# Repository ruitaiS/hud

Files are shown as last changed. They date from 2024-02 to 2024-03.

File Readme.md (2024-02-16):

## 2-15:

<div style="display: inline-block;">
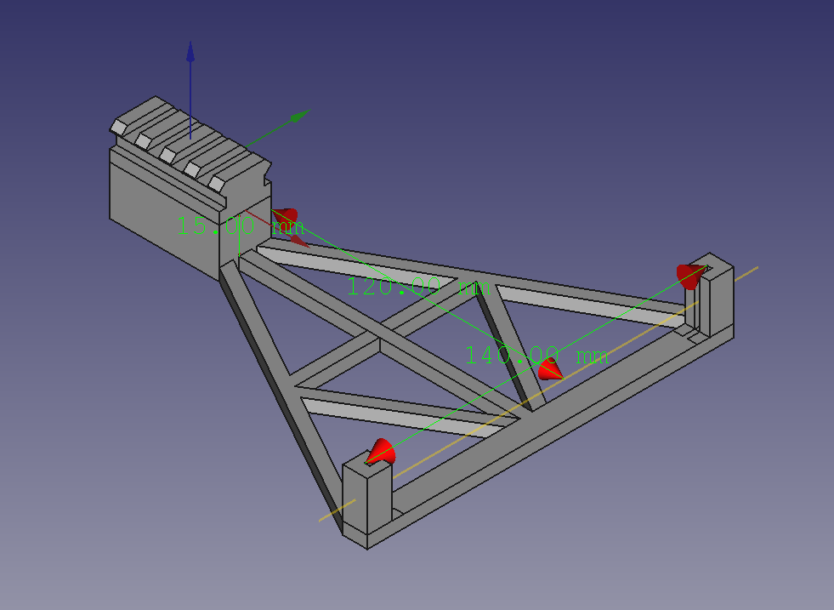
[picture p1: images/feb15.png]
    
    
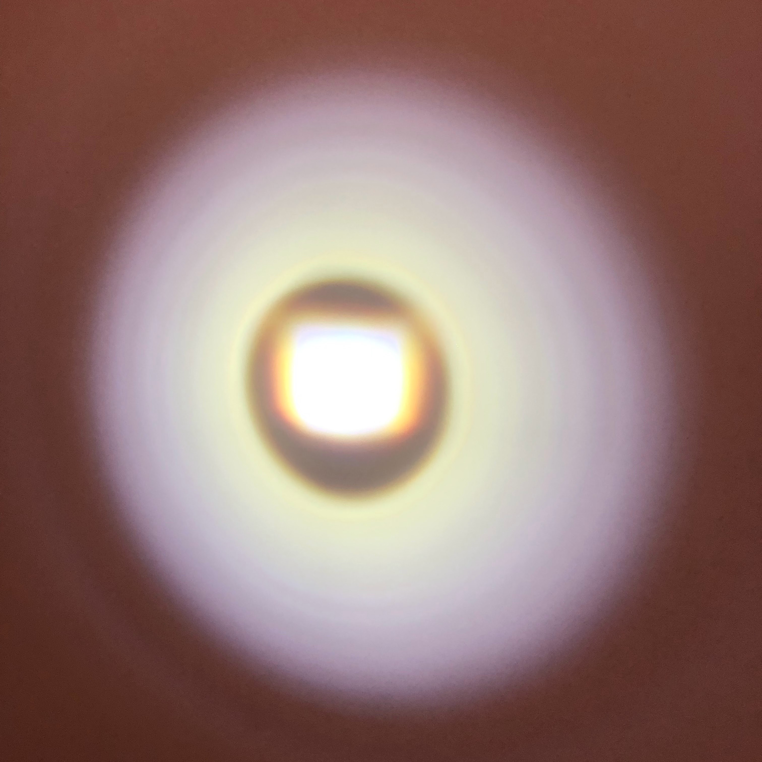
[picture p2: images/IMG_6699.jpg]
    
</div>

### Notes:
Nice. Bracket fits, and I think the focal length is roughly correct. I think that's what it means when the LED stays in focus as I move it back and forth; tbh I don't understand optics super well. I think the projected light pattern is caused by the mirror in the LED housing bouncing the light at weird angles to the collimator lens (you can see the square LED itself in the center, surrounded by a halo), so next steps will be to take that off and design some way to make finer adjustments for focal length.

### Changes:
- Lens bracket width fixed
- Light mount height offset increased from 0 to 15mm
- Infill Density reduced from 100% to 10%

### Print Settings:
Layer Height: 0.12 mm  
Wall Thickness: 1.2 mm  
Wall Line Count: 8  
Horizontal Expansion: 0.0 mm  
Top/Bottom Thickness: 0.84 mm  
Top Thickness: 0.84 mm  
Top Layers: 7  
Bottom Thickness: 0.84 mm  
Bottom Layers: 7  
Infill Density: 10%  
Infill Pattern: Gyroid  
Printing Temperature: 220.0 C  
Build Plate Temperature: 60.0 C  
Print Speed 45.0 mm/s  
Fan Speed 100%  
Generate Support: True  
Support Placement: Everywhere  
Support Overhang Angle: 59.0 Deg.  
Support Horizontal Expansion: 0.8 mm  
Build Plate Adhesion Type: None 

## 2-14:

<div style="display: inline-block;">
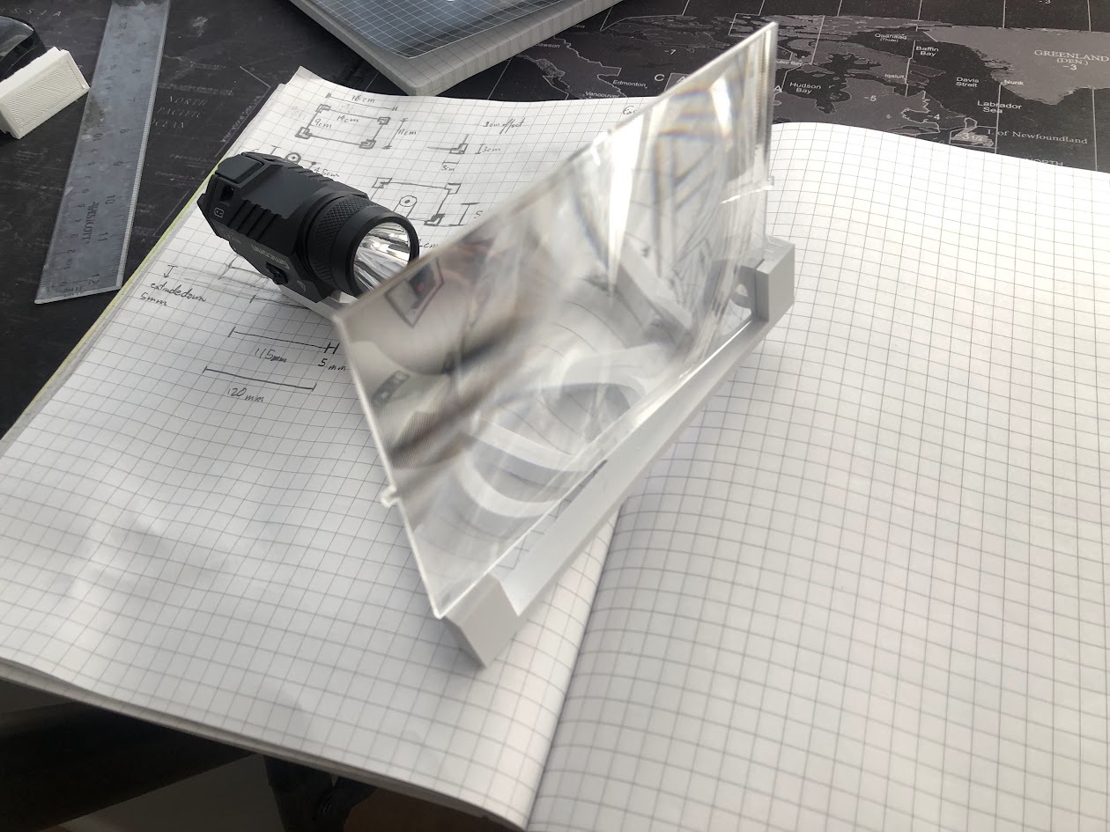
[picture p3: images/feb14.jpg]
    
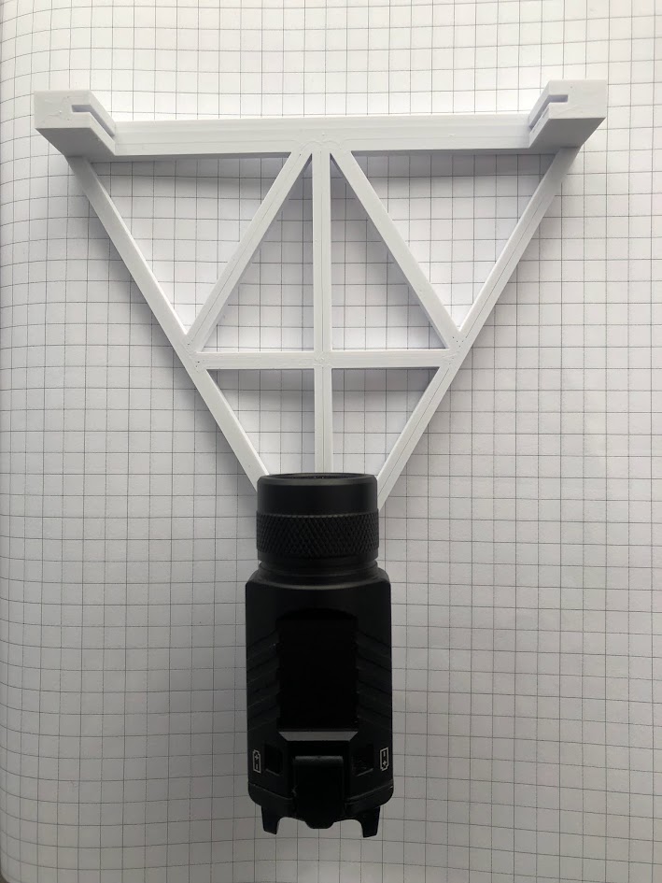
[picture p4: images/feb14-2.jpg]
    
</div>

### Notes:
I forgot to check the lens bracket width before printing it, so it didn't actually fit. Fixed it now, but it was kind of a foolish oversight. Not a total waste of time though; it was good to at least see a rough version irl and see what works and what needs fixed. The light mount was 15mm low after checking with a ruler; I'd originally calculated it by doing the height minus half the diameter of the housing, but it was easier to get a more accurate reading off the print. The rigidity is really good; triangles are really strong, so I'm pretty happy about that. A future project might be an analysis on the strength of different sized struts under tension / compression / bending, but for now good enough is good enough. Next print I'll try 10% infill; the struts and mounting points will still be solid because of the high wall count, but it'll save some time/material not filling in the bigger blocks. Build plate adhesion was fine; I was concerned because I couldn't fit a raft due to size constraints, but it turned out okay, so great.

### Print Settings:
Layer Height: 0.12 mm  
Wall Thickness: 1.2 mm  
Wall Line Count: 8  
Horizontal Expansion: 0.0 mm  
Top/Bottom Thickness: 0.84 mm  
Top Thickness: 0.84 mm  
Top Layers: 7  
Bottom Thickness: 0.84 mm  
Bottom Layers: 7  
Infill Density: 100%  
Infill Pattern: Gyroid  
Printing Temperature: 220.0 C  
Build Plate Temperature: 60.0 C  
Print Speed 45.0 mm/s  
Fan Speed 100%  
Generate Support: True  
Support Placement: Everywhere  
Support Overhang Angle: 59.0 Deg.  
Support Horizontal Expansion: 0.8 mm  
Build Plate Adhesion Type: None

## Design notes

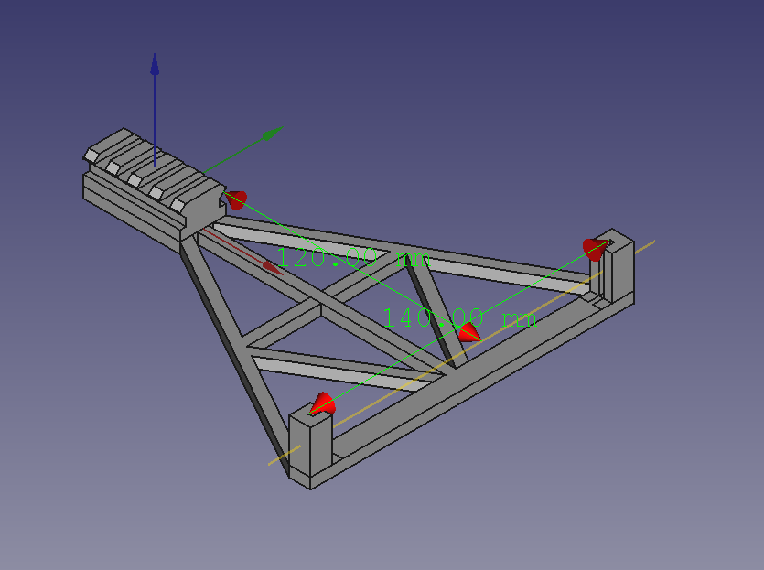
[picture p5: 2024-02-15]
images/combined.png

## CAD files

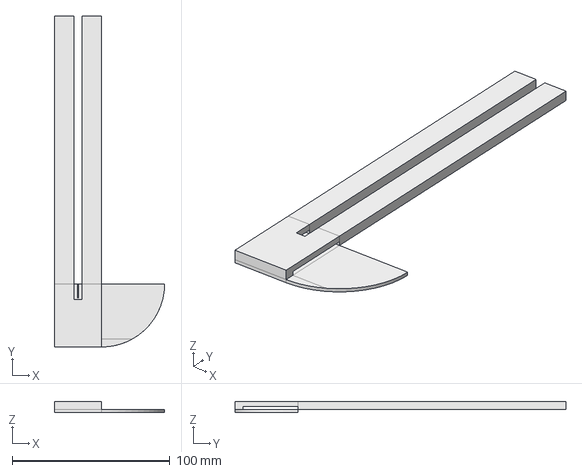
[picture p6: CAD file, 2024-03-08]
cutting-guide.FCStd
70.0 x 210.0 x 6.70 mm

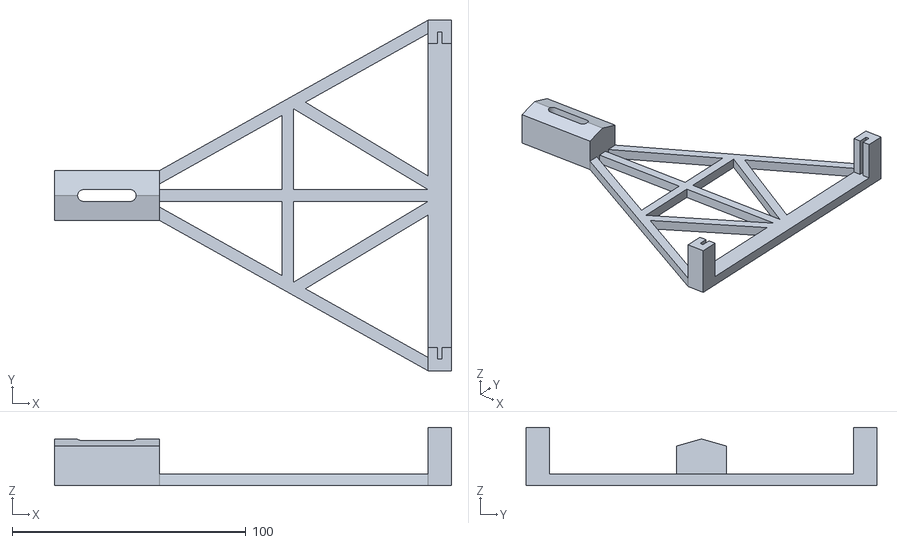
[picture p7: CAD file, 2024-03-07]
bracket.stl
169.8 x 150.0 x 25.0

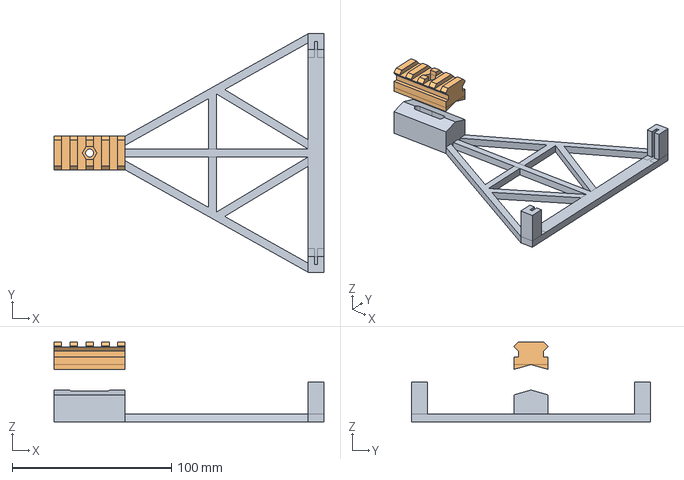
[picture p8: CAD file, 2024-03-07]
light_mount_lower.FCStd
169.8 x 150.0 x 50.1 mm
Bracket
Moving_Rail

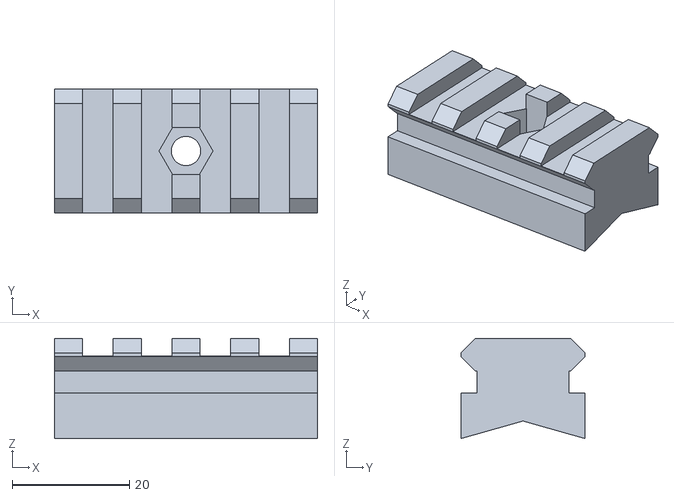
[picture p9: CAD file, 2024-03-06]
light_rail.stl
44.8 x 21.2 x 17.1

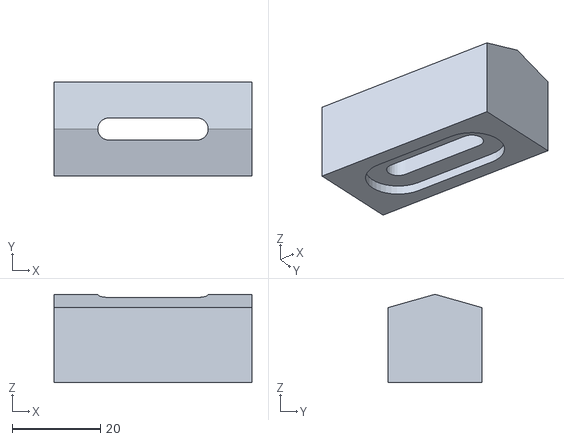
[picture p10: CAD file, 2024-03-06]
light_mount_lower-partial-Body003.stl
44.8 x 21.2 x 20.0

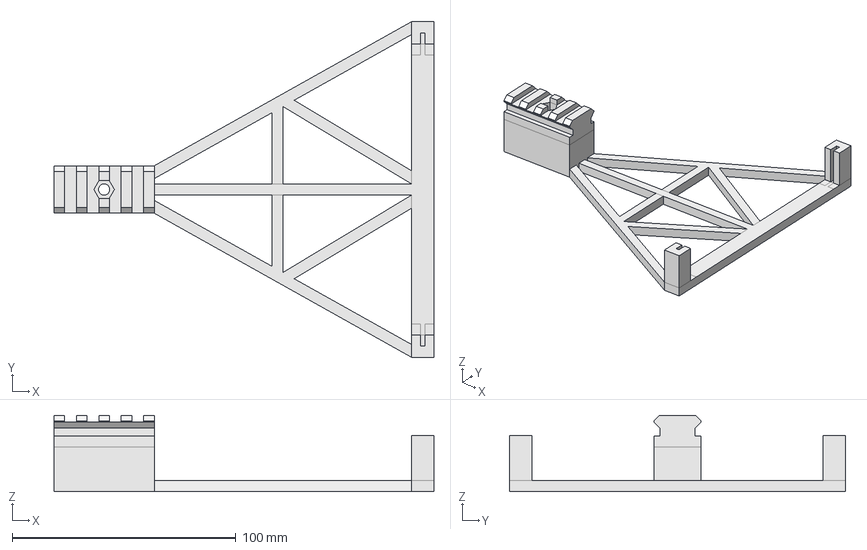
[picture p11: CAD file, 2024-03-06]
light_mount.FCStd
169.8 x 150.0 x 34.1 mm

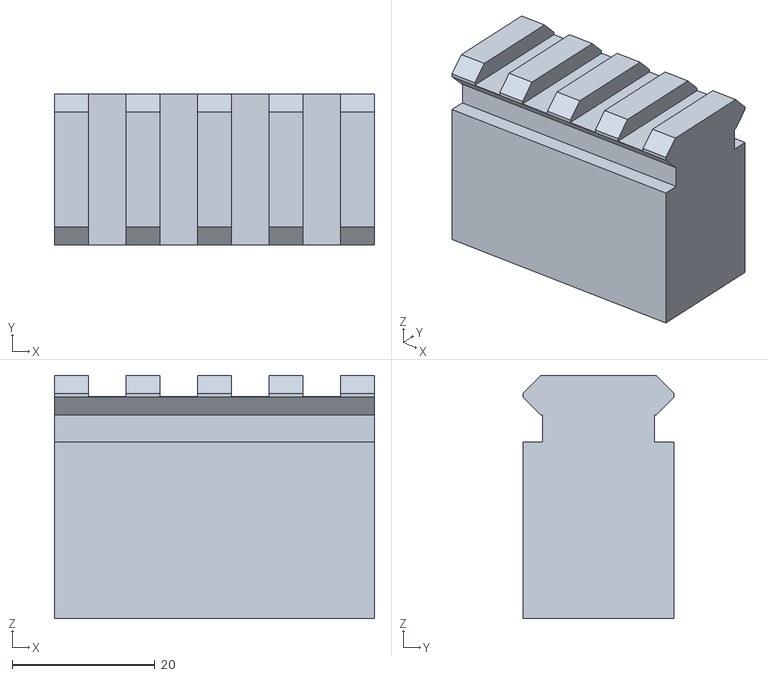
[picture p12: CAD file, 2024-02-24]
light_mount_sliced-Slice.stl
44.8 x 21.2 x 34.1

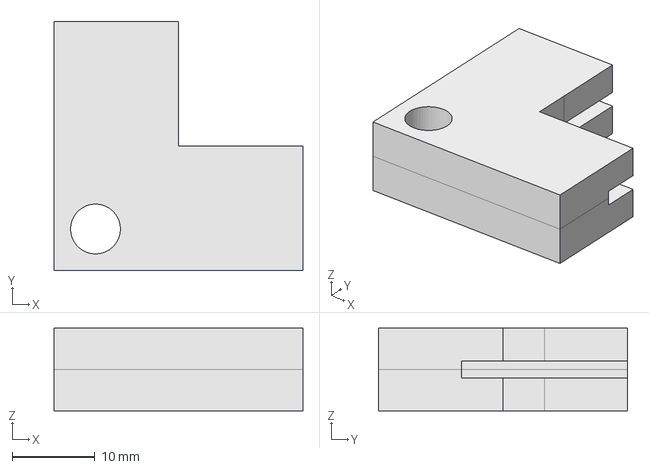
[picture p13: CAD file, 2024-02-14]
lens_mount.FCStd
30.0 x 30.0 x 10.0 mm

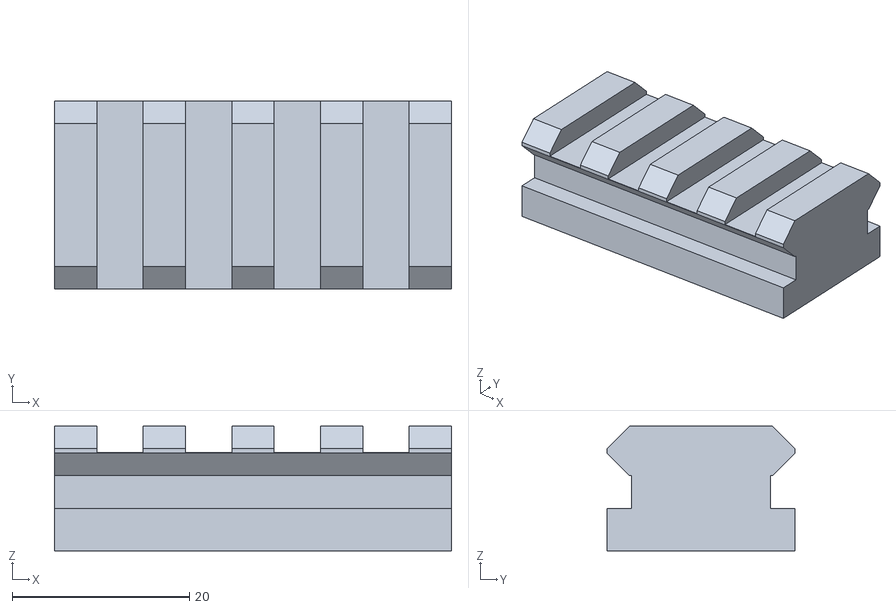
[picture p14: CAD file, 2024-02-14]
light_mount-Body.stl
44.8 x 21.2 x 14.1

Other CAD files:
light_mount_lower-Body001.stl
light_mount_3-6_backup.FCStd
combined-Body.stl
lens_mount-Body.stl
cutting-guide.stl

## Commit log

2024-02-15 base triangle
    [light_mount.FCStd]
2024-02-15 base pad reduced to 5.00001mm (5mm causes an intersect I guess)
    [light_mount.FCStd]
2024-02-15 collimator bar now proper width of 150mm
    [light_mount.FCStd]
2024-02-15 feb 14 print
    [combined-Body.stl]
2024-02-15 fixed lens bracket gap
    [light_mount.FCStd]
2024-02-15 added labels for photo
    [light_mount.FCStd]
2024-02-15 feb15 print
    [combined-Body.stl]
2024-02-15 added readme, more photos, updated files
    [combined-Body.stl, light_mount.FCStd]
2024-03-06 hex pocket
    [light_mount.FCStd]
2024-03-06 backup + progress
    [light_mount.FCStd, light_mount_3-6_backup.FCStd, light_mount_sliced.FCStd]
2024-03-06 mar 6 print
    [light_mount_lower-Body001.stl, light_mount_lower-Body002.stl, light_mount_lower-partial-Body003.stl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]
